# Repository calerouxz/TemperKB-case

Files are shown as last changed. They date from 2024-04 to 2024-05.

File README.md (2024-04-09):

# Temper Gasket Case
This is a case for [Raeedcho's **Temper**](https://github.com/raeedcho/temper) keyboard.

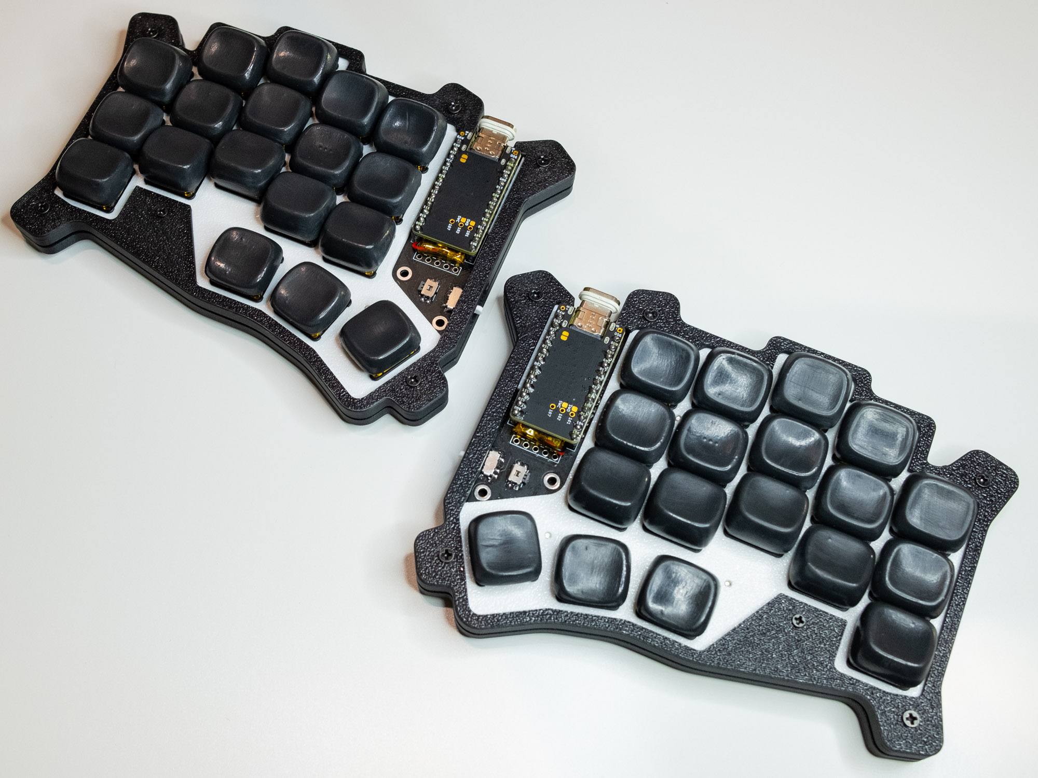
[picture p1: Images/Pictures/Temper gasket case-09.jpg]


## Objectives for the case
When designing this case for the [**Temper**](https://github.com/raeedcho/temper), I had the following objectives:

1. Include a 'gasket' mounting method.
2. Add some refinement to the case, creating a more end-product feeling design.
3. Include an easier to use on/off switch that fits onto the small one on the board.

## Documentation
The following documentation is meant to help you build the case:

1. [BOM (Bill of Materials)](Documentation/bill%20of%20materials.md)
2. [3D print guide](Documentation/print%20guide.md)
3. [Build guide](Documentation/build%20guide.md)
4. [Change log](Documentation/changelog.md)

## Complexity
Keep in mind that this is a relatively complex assembly and *does* require additional hardware (screws, heat-set inserts and o-rings). There is also a fair amount of 3D printed parts that need to fit together. 

## Pictures

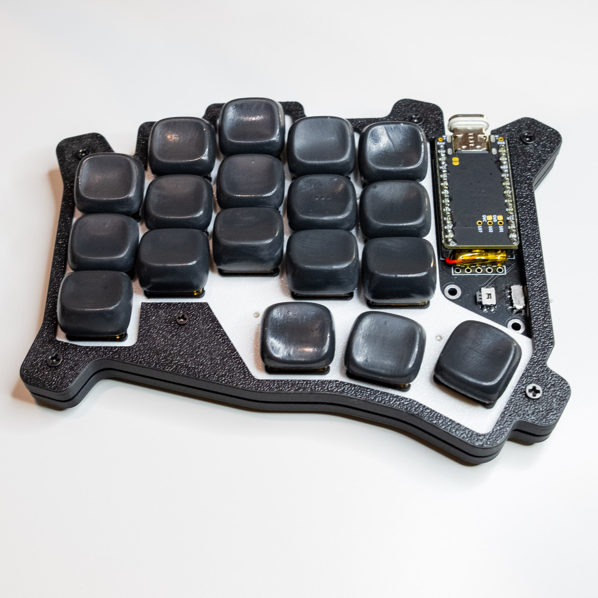
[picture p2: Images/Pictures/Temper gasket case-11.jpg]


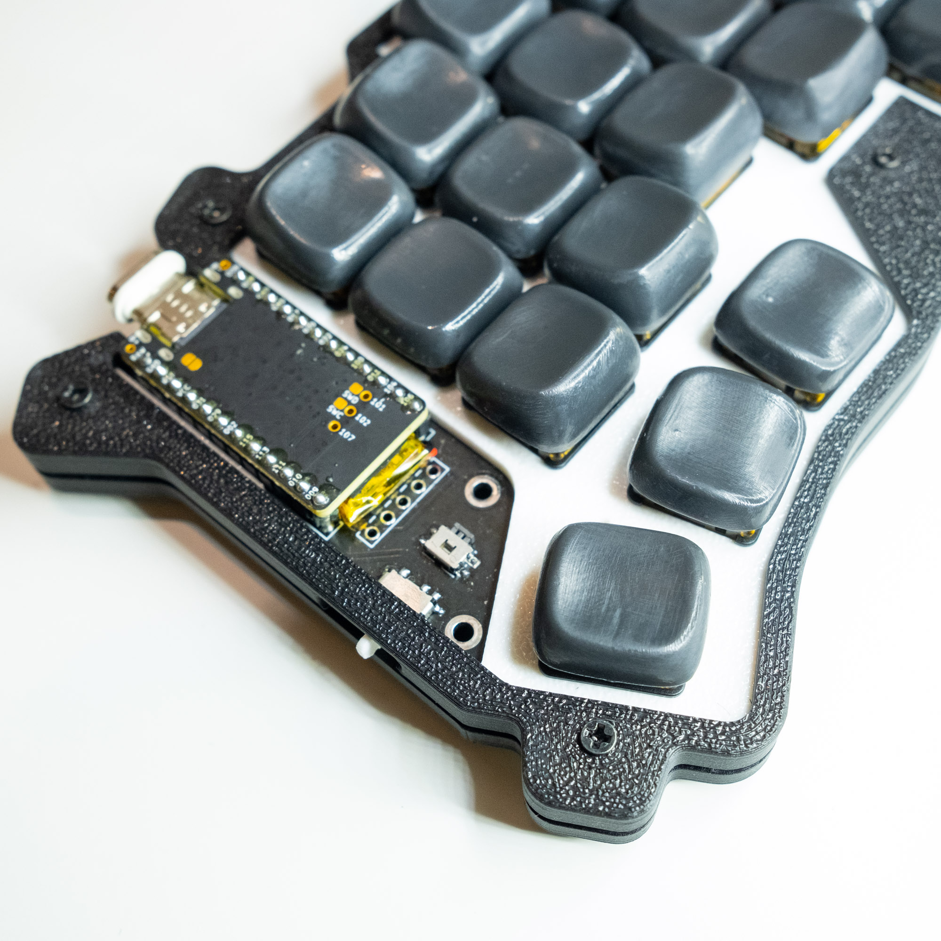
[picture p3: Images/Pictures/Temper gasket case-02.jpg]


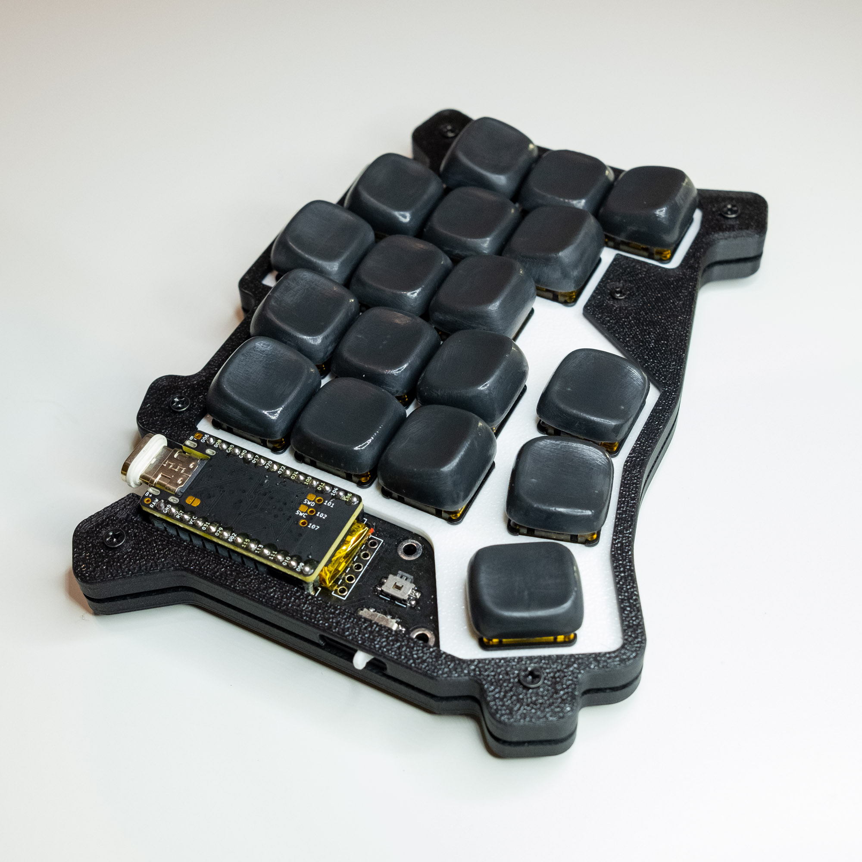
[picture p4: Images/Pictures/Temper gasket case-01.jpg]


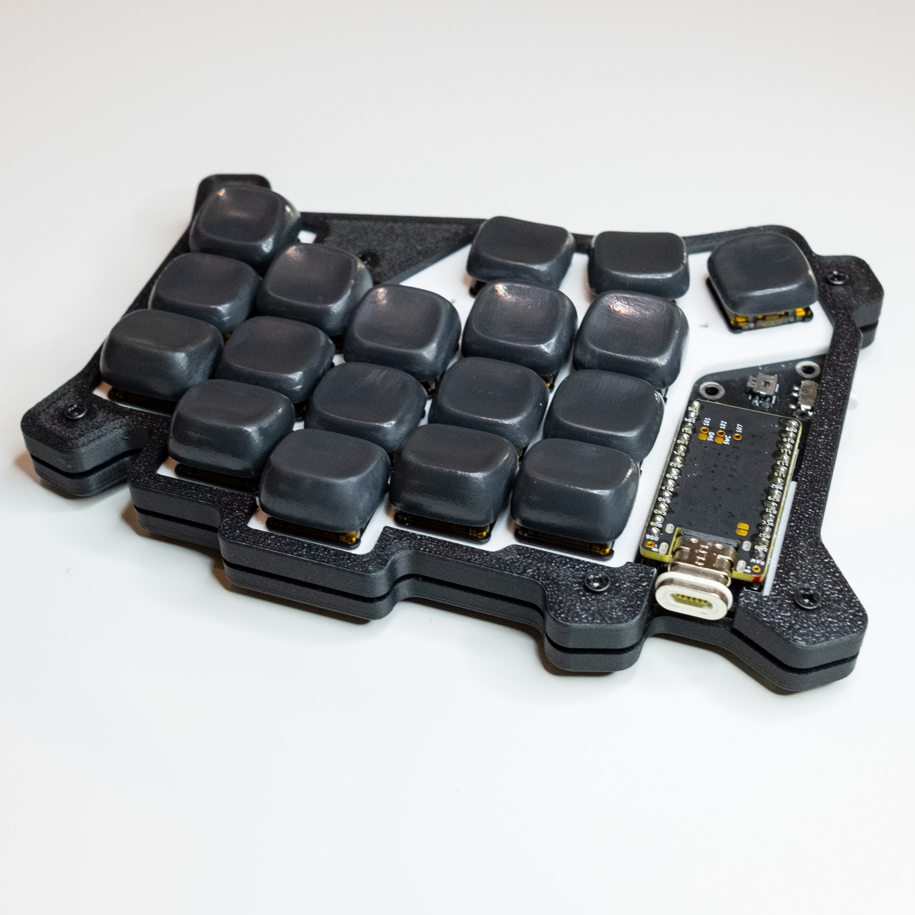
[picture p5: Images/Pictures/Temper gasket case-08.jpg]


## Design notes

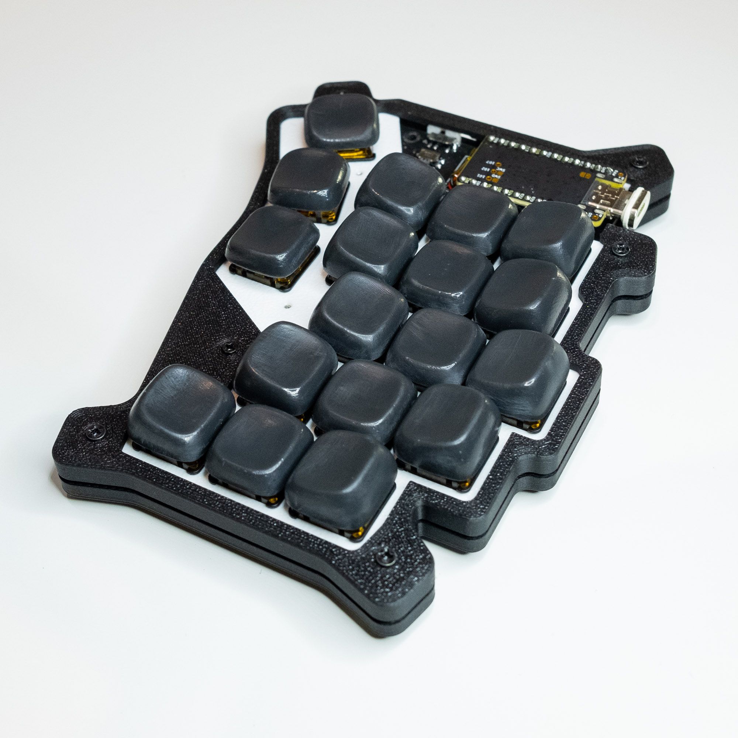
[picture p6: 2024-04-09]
Images/Pictures/Temper gasket case-05.jpg

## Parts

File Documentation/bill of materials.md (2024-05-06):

# Bill of materials for Temper gasket case

## 3D printed materials
Check the 3D print guide for details on how to print these parts.
|Material|qty|Comments|
|---|---|---|
|Switch plate, left|1|Mirror this left side to get the right side.|
|Switch plate, right|1||
|Supplemental PCB holder, left|1|Mirror this left side to get the right side.|
|Supplemental PCB holder, right|1||
|Case base, left|1|Mirror this left side to get the right side. There is a self-tap version of this model available if you don't want to use or have heat-set inserts. *keep in mind I have not tested the self-tap version myself.*|
|Case base, right|1||
|Case top cover, left|1|Mirror this left side to get the right side.|
|Case top cover, right|1||
|Power switch covers|2||

## Other required materials
|Material|qty|Comments|
|---|---|---|
|M2x3mm Heat-set inserts|8|These are for the pockets and go below the o-rings. **Not needed if using the self-tap base.**|
|M2x8mm flathead or buttonhead screws|8||
|M2x4mm heat-set inserts|2|These are for the single post meant to hold the hollow area on the top cover. **Not needed if using the self-tap base.**|
|M2x6mm flathead or buttonhead screws|2||
|M2x3mm flathead or buttonhead screws|10|These will hold the PCB to the switch plate.|
|1.5mm thickness, 3mm ID / 6mm OD o-rings|10|Can be either rubber or silicone. I used rubber for my first print. *Alternatively* you could cut neoprene or other materials to fit.|

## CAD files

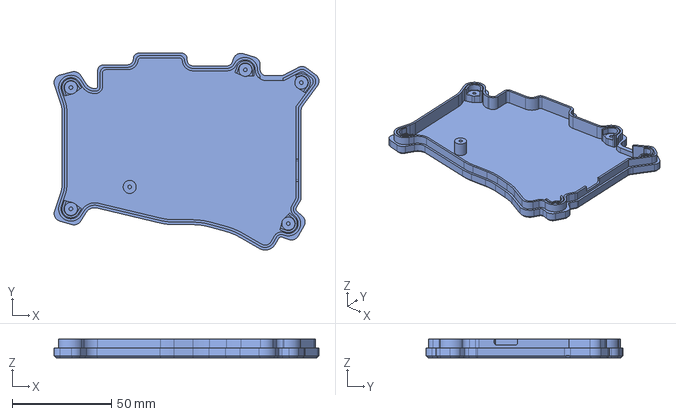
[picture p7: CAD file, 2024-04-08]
Print files/Gasket case parts - Case Base - Self Tap.step
133.6 x 99.4 x 9.40 mm

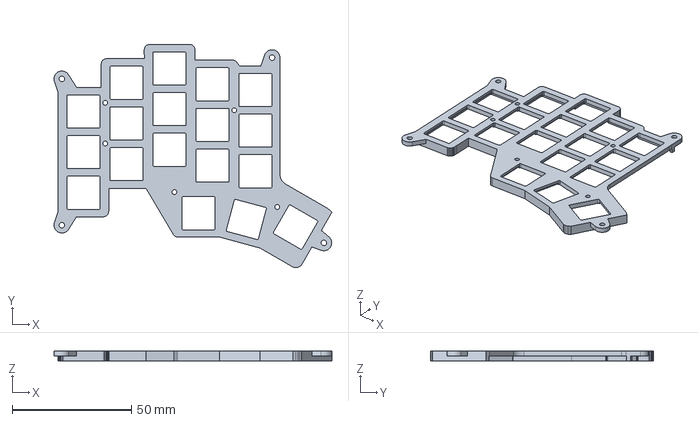
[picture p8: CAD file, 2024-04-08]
Print files/Gasket case parts - Switch Plate.step
116.3 x 93.4 x 4.00 mm

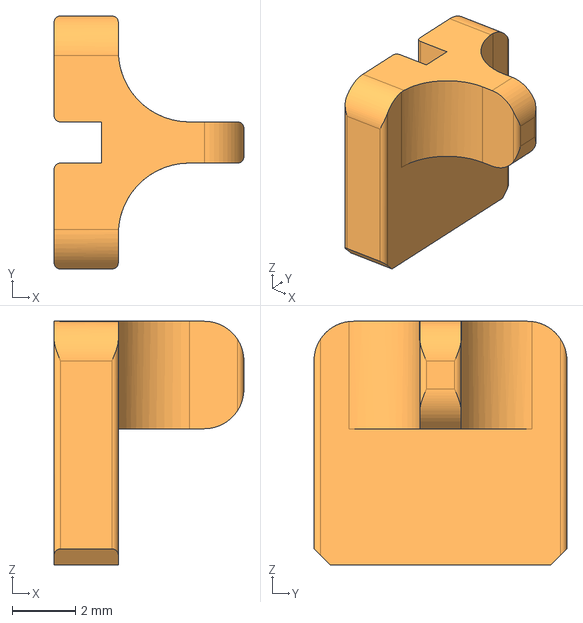
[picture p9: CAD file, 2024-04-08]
Print files/Gasket case parts - Power SW.step
6.00 x 8.00 x 7.70 mm

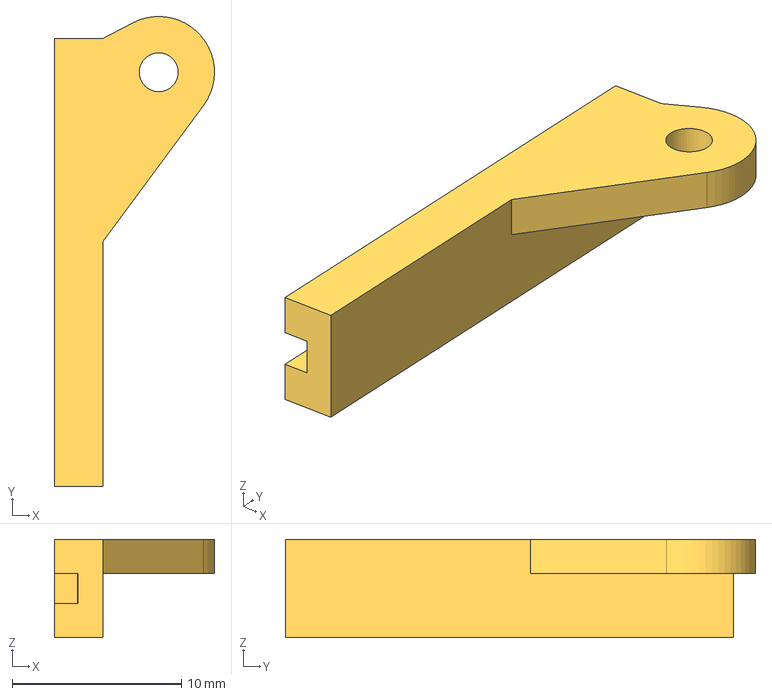
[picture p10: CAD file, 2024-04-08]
Print files/Gasket case parts - PCB holder.step
9.46 x 27.8 x 5.80 mm

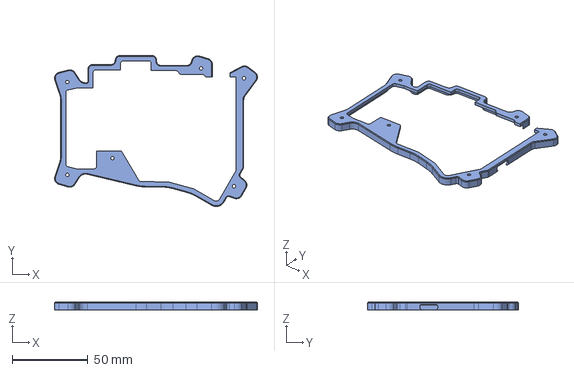
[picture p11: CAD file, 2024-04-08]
Print files/Gasket case parts - Case Top.step
133.6 x 99.4 x 5.00 mm

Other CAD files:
Print files/Gasket case parts - Case Base - Heatsets.step

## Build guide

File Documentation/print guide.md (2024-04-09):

# Print guide
For context, I printed all parts using a Bambulab A1, using a 0.16mm layer height on all parts. 0.20mm layer heights will work as well.

I designed most parts with a 0.20mm tolerance value. Using these values should give a tight fit.

The holes on the switch plate and top cover have a 0.30mm tolerance value to make it easier to introduce the screws.

Self-tap holes (on the **switch plate** and the optional **self-tap case base**) will have a 1.9mm hole (-0.01mm to standard M2) to get a tight fit.

I made the case available on Makerworld for those who own Bambulab printers: [Link to the case on Makerworld](https://makerworld.com/en/models/420450#profileId-323142)

## Switch plate
The switch plate is not particularly difficul to print, but be mindful of your filament and the large flat area it requires, as with some filaments it could lead to warping. 

I *recommend* printing this part in PET-G as it will minimally bend and deform on the pockets while typing. PET-G may prove to be a more durable material for this particular part, but I also tested these in PLA and they worked fine.

I printed the part using white polymaker PET-G and did not have any issues.

Mirror the left side to get the right side.

## Supplemental PCB holder
The supplemental PCB holder is probably the hardest part to print due to the horizontal overhang needed to fit it onto the PCB, which needs supports.

I printed this part face-side down and then used supports on the cavity. This was done to preserve accuracy on the mount area.

You can *try* to print this part in other orientations if you choose to avoid supports (**not tested by myself**).

I printed the part using white polymaker PET-G.

Mirror the left side to get the right side.

## Power switch covers
This part does **not** require to be mirrored.

Print this part with the point facing up. You will have a small overhang between the bases, in various prints this has not been an issue.

I printed the part using white polymaker PET-G.

## Case base
The case base has quite intricate details on the mounting pockets.

I suggest turning on supports for the small pockets for the feet on the bottom, this will allow them to be cleaner.

Some filaments will require heavy brims to ensure you get no warping due to the large flat surface. 

I printed using Bambulab matte charcoal PLA. This particular filament did prove problematic due to warping on some of my test prints. I had to clean the plate and use heavy brims to get the quality I wanted. I also did a test print in Hatchbox orange PLA with no issues using no brims.

I have made available a self-tap version of the base model, having a 1.9mm screw clearance. Keep in mind I have personally not tested this version of the case.

## Case top cover
The top cover should have similar settings to the case base. This part may or may not use brims debending on your particular filament. My particular filament did require a brim in order to keep warping to a minimum.

I printed using Bambulab matte charcoal PLA.

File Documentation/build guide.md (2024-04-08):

# Build guide
## Preparing the case base

> [!IMPORTANT]
> If you use the self-tap variant of the case, you can skip this step.
> Keep in mind, this version of the case is **untested** by myself.

You will first need to prepare the case base, inserting the heat-set inserts onto the base. You can use a soldering iron for this operation.

- Insert 5 M2x3mm heat-set inserts into the mounting pockets. Repeat for the other side.
- Insert 1 M2x4mm heat-set insert into the pole to hold the top cover. Repeat for the other side.

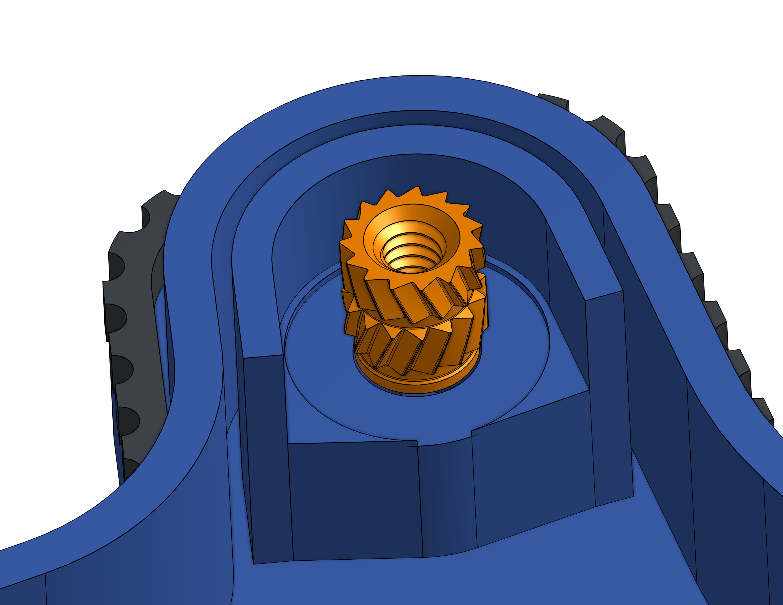
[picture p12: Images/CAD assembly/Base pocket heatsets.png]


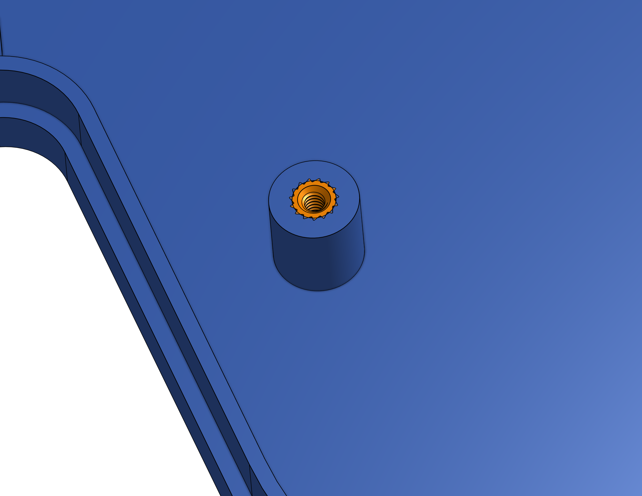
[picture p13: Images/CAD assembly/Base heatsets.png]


## Preparing the PCB assembly
1. Place the PCB onto the switch plate, making sure it is fully seated.

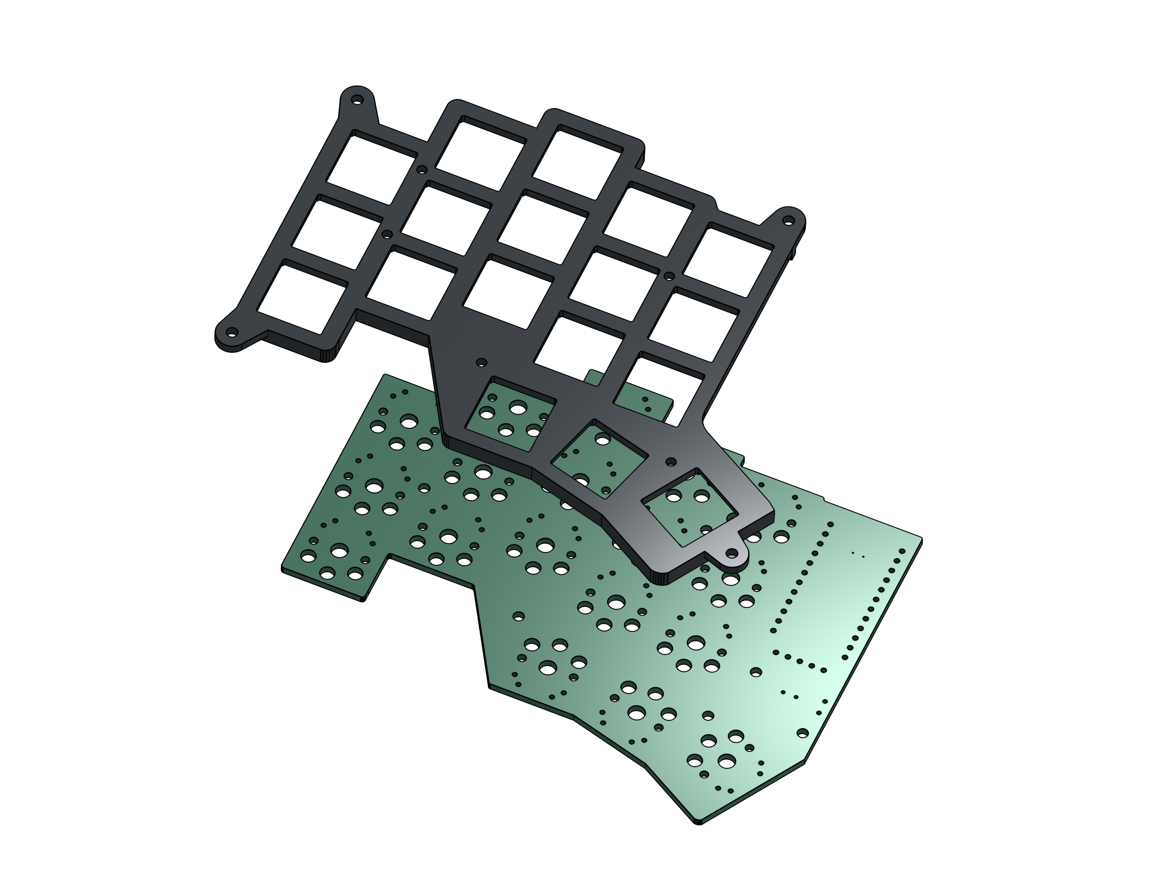
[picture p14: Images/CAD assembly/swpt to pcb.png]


2. Screw on the 5 M2x3mm screws frome the bottom of the PCB to the switch plate. These should self-tap onto the switch plate.

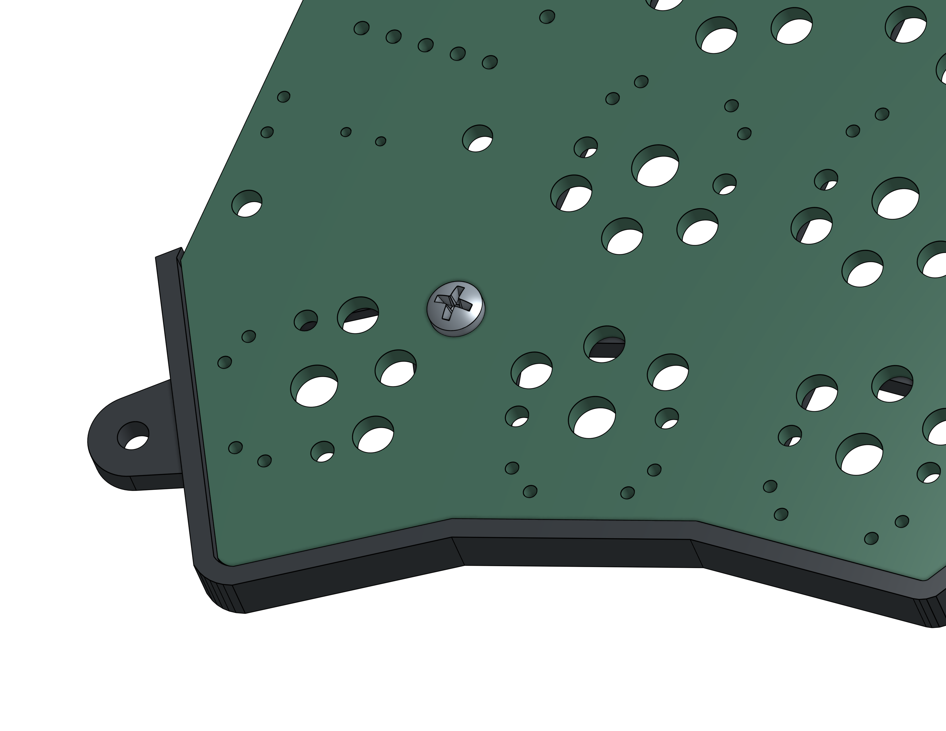
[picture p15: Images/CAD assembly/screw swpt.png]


3. Turn the assemby over and place your switches on the assembly.
4. Place the supplemental PCB holder on the PCB, right next to the MCU.

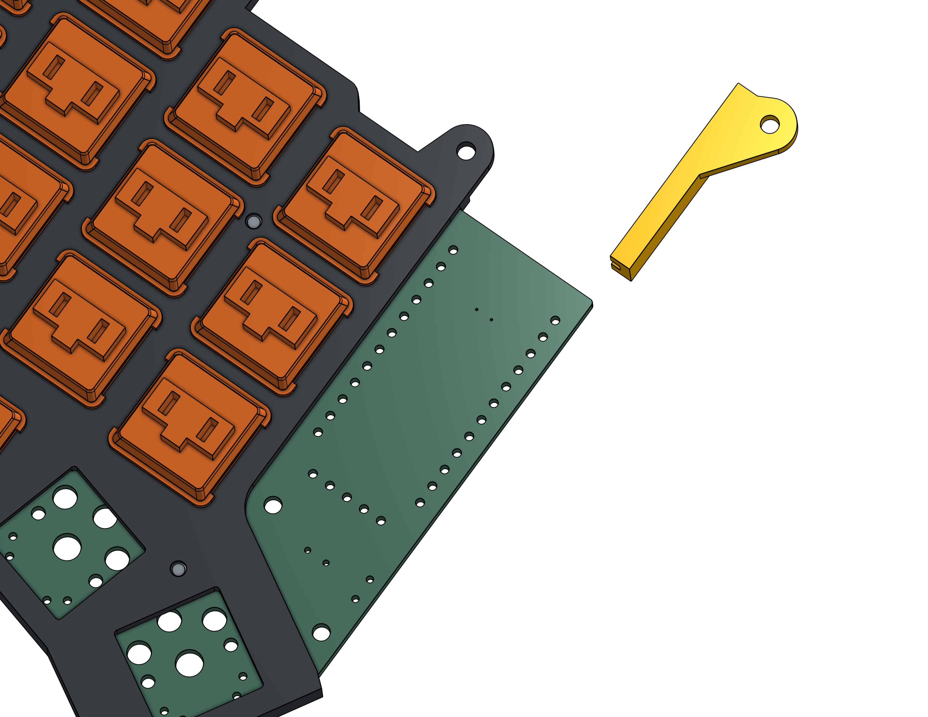
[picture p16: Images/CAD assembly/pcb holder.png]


Repeat these 4 steps on the other side.

This is how the completed assembly should look like:

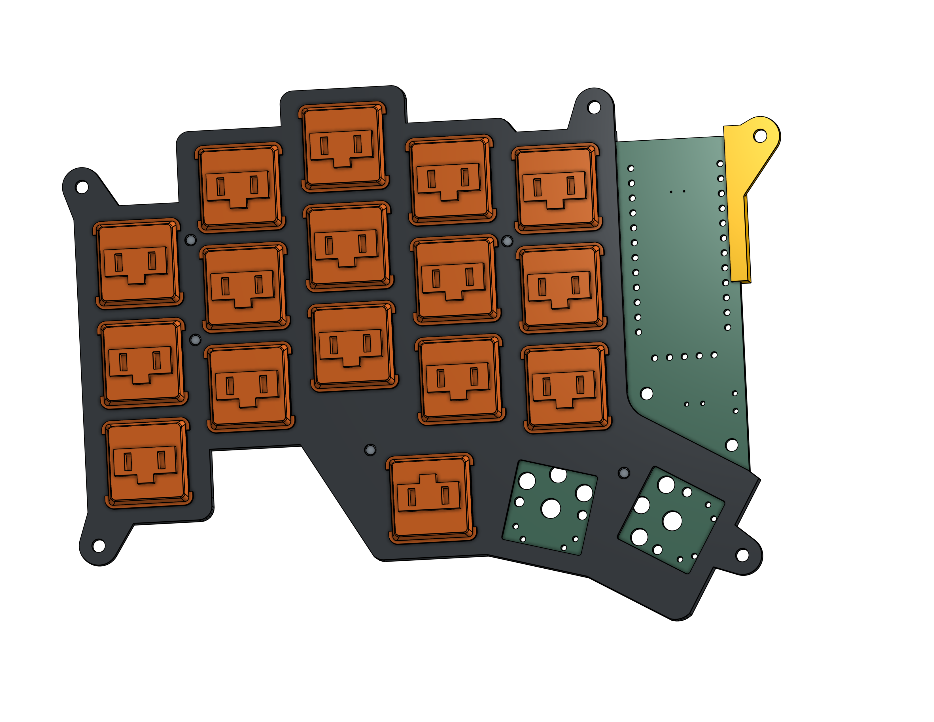
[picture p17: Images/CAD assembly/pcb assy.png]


## Assemble the keyboard
1. Place 5 o-rings on their respective pockets on the **case base**.

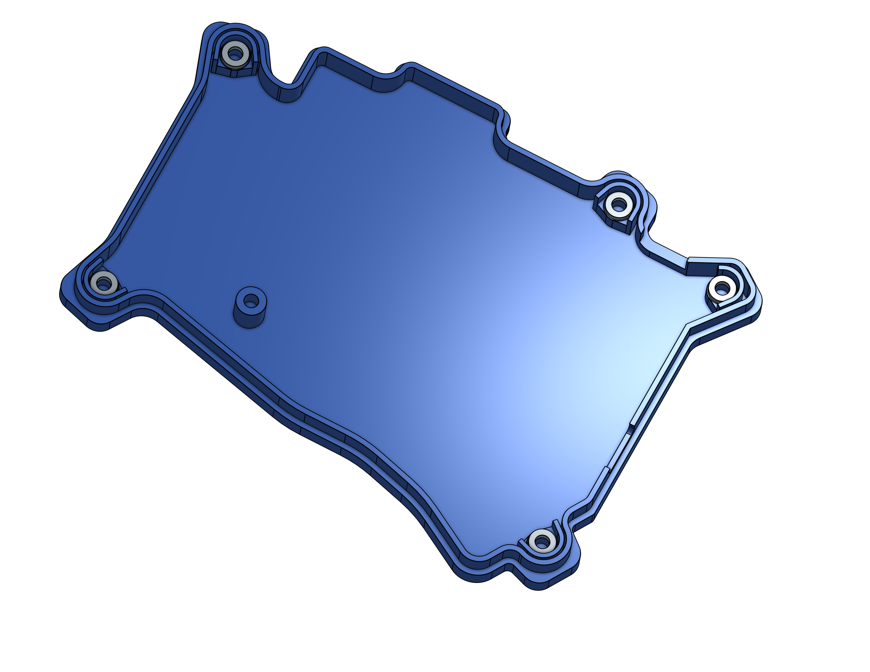
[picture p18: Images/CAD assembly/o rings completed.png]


2. Place the PCB assembly on the case base, making sure the mounting points line up over the o-rings and their pockets.

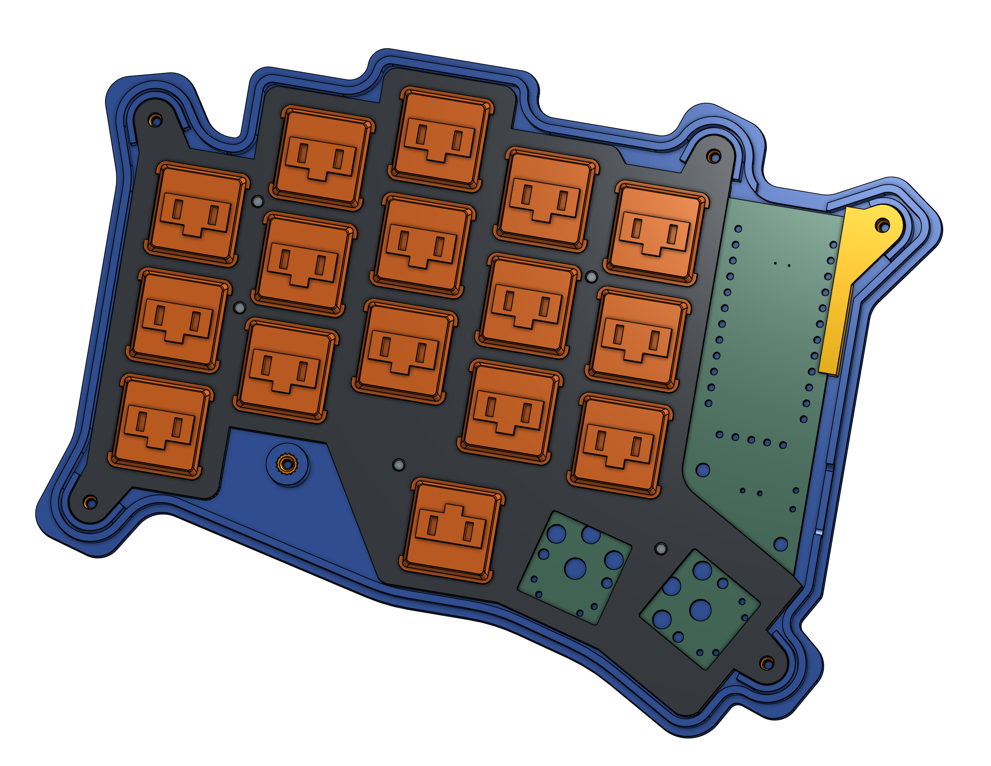
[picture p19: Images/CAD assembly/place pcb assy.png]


3. Place the power switch cover, lining up the small tab on the on/off switch with the power switch cover's slot.

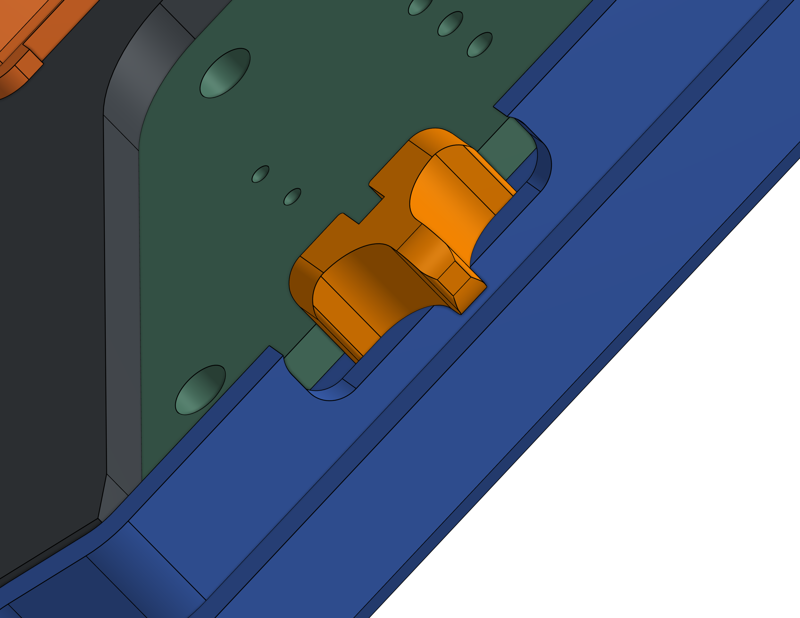
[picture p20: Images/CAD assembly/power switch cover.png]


4. Place the top cover on the case base.

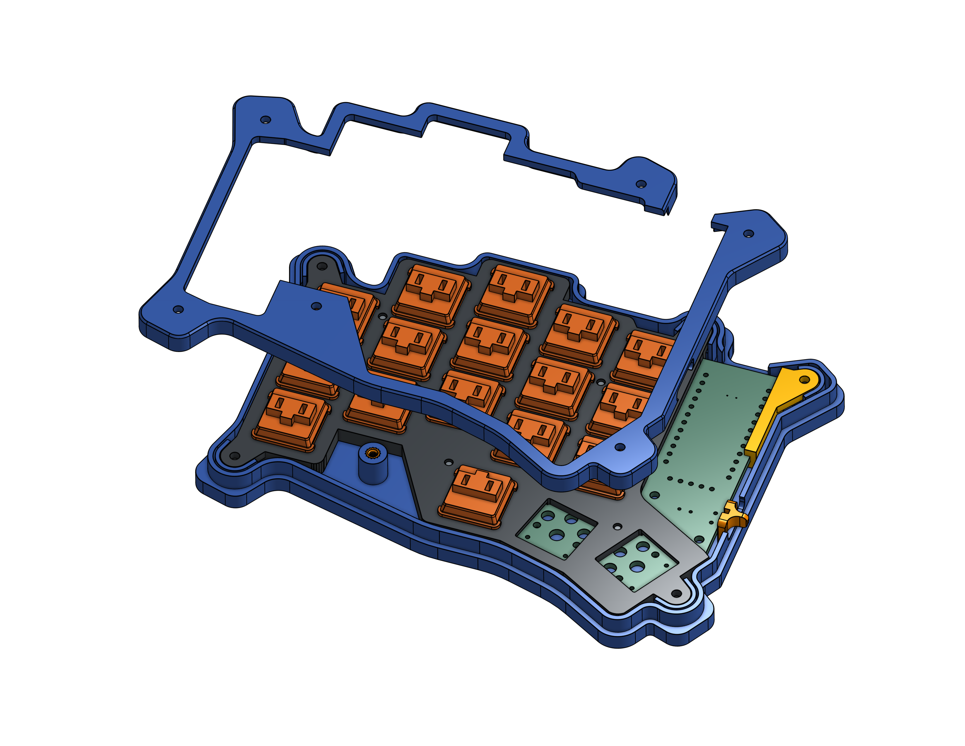
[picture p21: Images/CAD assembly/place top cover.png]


5. Screw 5 M2x10mm screws on protrusions, These should line up with the switch plate and o-ring.

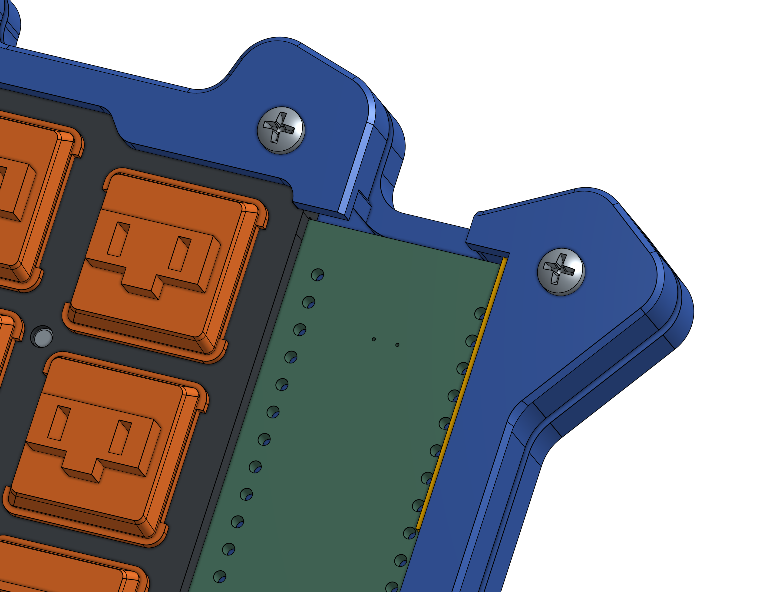
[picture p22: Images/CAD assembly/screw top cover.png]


6. Screw 1 M2x6mm screw on the additional tab of the top cover to secure it to the bottom base.
7. Place the feet on the bottom of the assembly.

Repeat these 7 steps on the other side.

This is how the completed case assembly should look like:

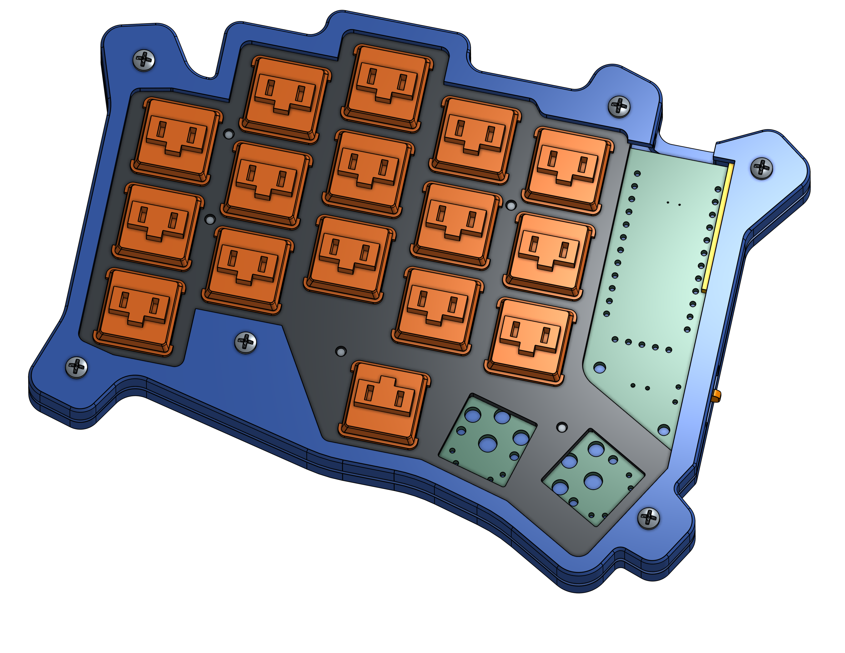
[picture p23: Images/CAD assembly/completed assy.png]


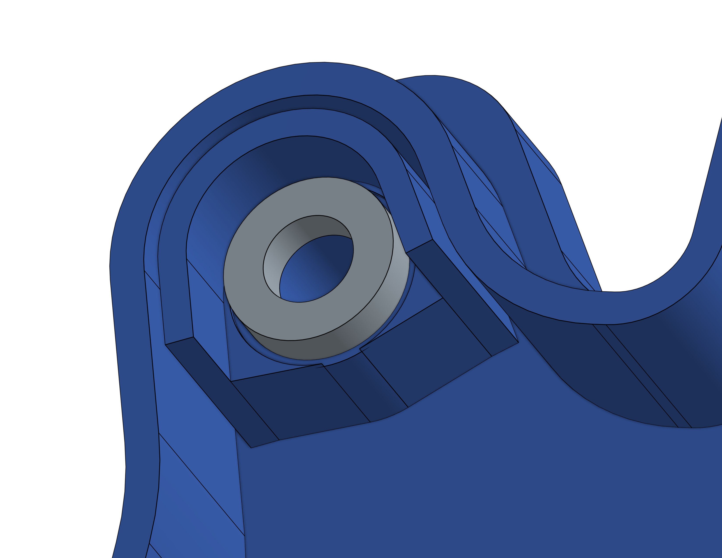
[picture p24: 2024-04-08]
Images/CAD assembly/case oring.png

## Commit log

2024-04-08 added 3D print files
    [Gasket case parts - Case Base - Heatsets.step, Gasket case parts - Case Top.step, Gasket case parts - PCB holder.step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]
2024-04-08 added self tap base
    [Gasket case parts - Case Base - Self Tap.step]
2024-04-09 Update print guide.md with info on case top cover filament
2024-05-06 Update BOM to include specific type of screws.
